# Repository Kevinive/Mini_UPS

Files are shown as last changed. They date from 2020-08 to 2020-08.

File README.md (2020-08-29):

# Mini_UPS
A Low-Voltage UPS designed for dormitory.

一个在宿舍断电后为宿舍位基本用电器供电的UPS。

### 1 项目介绍

宿舍断电后一篇漆黑，无法继续进行学习，也无法对手机、笔记本进行充电，更无法使用寝室位的内网，因此开发了这个小项目。使用一个12V的铅蓄电池储存电能，在断电后为低电压宿舍用电器供电，以此改善宿舍生活品质。

### 2 功能介绍

#### 此系统实现了以下功能：

- 电池管理：对于铅蓄电池的电量进行管理，自动评估是否需要充电，若需要充电则在白天对电池进行充电。

- 电源预切换：由于检测到断电后再对电源进行切换会造成宿舍桌面用电器重启的情况，因此通过预设定固定的计划断电时间，让系统在市电掉电之前就将电源切换至电瓶。

- 多电压输出：同时输出24V、12V和5V的电压，为多种用电器供电。

#### 此系统还可实现以下功能：

- 联网控制：通过无线射频模块与寝室中控联络，接受统一控制。

### 3 文件介绍

ProgramBrief.docx ： 项目的具体设计细节

#### src/ ： 主程序代码相关文件

- UPSMain.ino ： 主程序

- UPS_config.h ： 若干UPS控制参数

- OLED.cpp/.h ： OLED屏驱动库

- WDTwake.cpp/.h ： 使用看门狗计数器唤醒程序的功能库

- NRF24L01forArduino.cpp/.h ： 无线通信模块驱动库（待开发）

#### lib/ ： 驱动库

#### circuit/ ： 电路设计文件

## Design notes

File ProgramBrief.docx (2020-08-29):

1系统模块图：

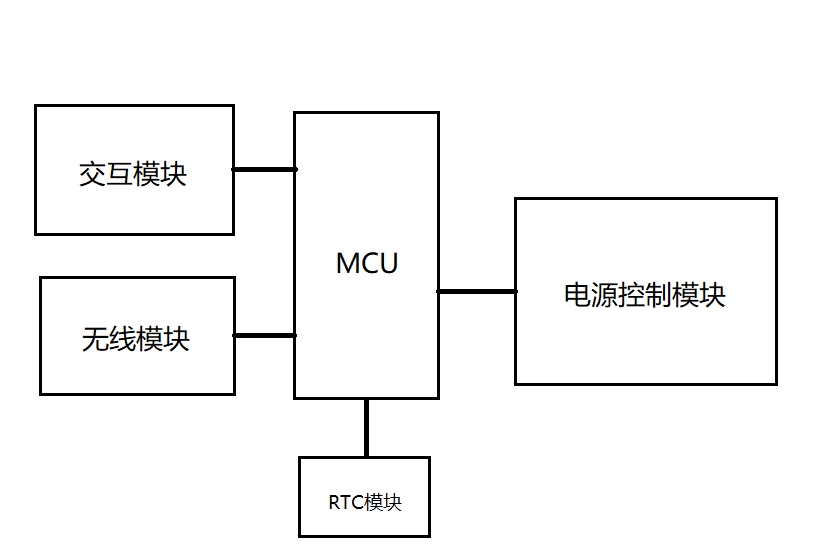
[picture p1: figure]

2模块功能要求：

1） 电源控制模块要求：在MCU的控制下进行电源切换；在MCU的控制下对电瓶进行充电（充电与停止充电）；在MCU的控制下对单片机进行断电（防止电瓶过放）；在外部按钮的控制下对MCU进行启动（MCU断电情况下无法自启动）；对MCU供电；（显示当前电量）（可以不实现）；
2） MCU：从RTC获取信号；根据时间控制电源模块进行电源切换；根据电瓶电压控制电源模块对电瓶进行充电（充电与停止充电）；在无电源且电瓶过放的情况下控制电源模块对自身进行断电；从无线模块接收指令并执行；通过交互界面让用户进行设定；交互界面超时熄灭；
3） RTC模块：设定时间后通过中断形式给MCU发送信号；自身有准确的实时时间，自带电源。
4） 无线模块：NRF24L01
5） 交互模块：由OLED显示屏、按键组成，能够独立设置参数并保存。

电源模块设计：

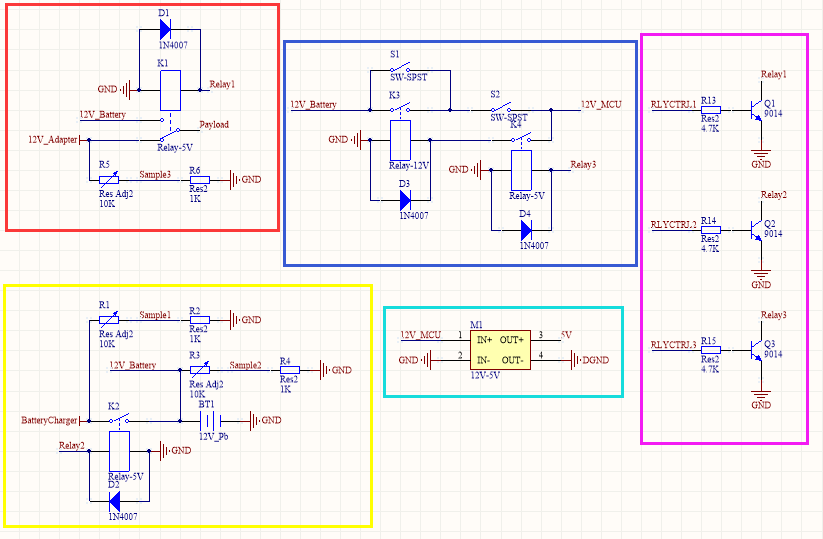
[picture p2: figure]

电源部分由一个12V的铅蓄电池、4个继电器、1个12V-5V的MCU供电模块和若干采样电阻组成。

12V电源切换部分，由一个MCU控制的5V继电器构成，控制着电源的切换（切换时间<20ms）。同时在12V电源适配器端有采样电路供单片机获取当前电压。

12V电瓶充放电电路，由一个12V铅蓄电池，一个MCU控制的继电器、电池充电器和电压采样电路组成。单片机通过电瓶电压和充电器电压采样电路可以获得相应电压，在电瓶电压不足时控制继电器吸合以为电瓶充电。

MCU供电开关电路，由两个继电器和一个开关控制，形成一个自锁开关电路。K3常开、K4常闭。一开始时K3断开，K3之后电路无电源。当按下外部开关S1后，电流流经K3控制回路，吸合K3，形成自锁，此时松开S1，后部分电路仍保持供电。当MCU检测到电瓶电压不足，为了保护电瓶，给K4控制回路上电，断开K4，使得K3断开，之后电路恢复断开的情形。

MCU电压转换电路，使用成品LM2596S芯片进行电压转换，电路成熟，可靠度高。

电流放大模块，使用三极管将控制电流放大，以实现单片机控制继电器。

RTC时钟模块：

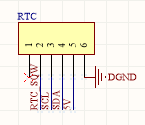
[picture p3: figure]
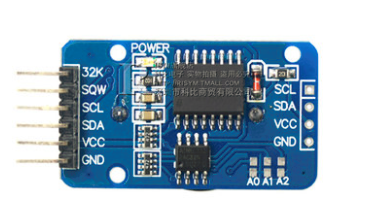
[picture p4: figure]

RTC时钟使用DS3231模块，此模块使用I2C通信，同时带有片上EEPROM。其时钟精度满足要求。工作过程中，将使用其SQW引脚向外周期发送信号，以唤醒MCU进行一系列的工作任务。同时提供矫正过的真实世界时间数据。

无线模块：

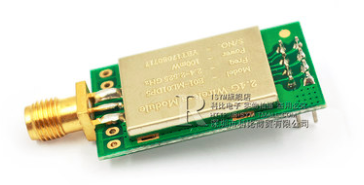
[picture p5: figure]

使用NRF24L01与主控设备或其他设备进行通信，同时可接收远程指令，包括但不限于：校准时间、手动断电、更改计划等。

交互模块：

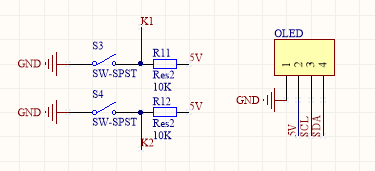
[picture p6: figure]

交互模块由一个OLED显示屏与两个按键组成。OLED屏选择使用I2C接口的128*64标准OLED，最大化利用I2C总线。按键S2和S3通过一段接地，另一端接MCU的输入端口，MCU输入端口提供上拉。

MCU：

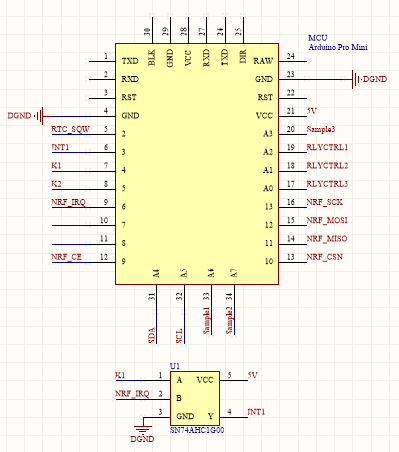
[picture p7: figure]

MCU选择Arduino pro mini 这款微型开发板。其核心为8位ATMega328P主控芯片，并且将最小系统已经集成在板上，十分适合快速开发。片上也有硬件SPI与硬件I2C接口，在同等级MCU中资源比较丰富。

ATMega328P这款芯片有两个外部中断引脚，在电平跳变激活中断的设置下，可以实现将MCU从掉电模式唤醒。但是本系统需要支持3路外部唤醒信号：RTC中断、无线系统中断、S2中断。因此，根据其中断特性，使用一个与非门将无线系统中断和S2中断连接到同一个中端口，将RTC中断单独连接到一个中断口。

V1版本

具体实现：

模块名称 | 模块 | PIN | 备注
OLED | SDA | 7 | OLED使用软件I2C通信，有外部上拉
| SCL | 8
NRF | MOSI | 11 | NRF使用硬件SPI通信
| MISO | 12
| SCK | 13
| CSN | 10
| CE | 9 | 芯片使能引脚
| IRQ | 3 | NRF中断输入MCU中断引脚3
RLY | RLY1 | 16A2 | RLY使用模拟口作为数字输出
| RLY2 | 15A1
| RLY3 | 14A0
SMP | S1 | A6 | 电压信号输入
| S2 | A7
| S3 | A3
KEY | K1 | 2 | 作为中断输入MCU中断引脚2
| K2 | 4 | 作为普通输入MCU

中断资源：

中断源 | 中断作用
NRF-IRQ | 唤醒MCU；传输数据；控制
K1 | 唤醒MCU；人机交互；控制
WDT | 唤醒MCU；采集电压信息&时间信息；控制

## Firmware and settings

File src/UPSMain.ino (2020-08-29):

#include "Include.h"

uint8 UPS_rxAdd[] = {0x11,0x22,0x33,0x44,0x55};		//通道1的接收地址
uint8 Master_txAdd[] = {1,2,3,4,5};
uint8 nrfDataBuf[RXBUFSIZE] = {0};
uint8 displayFlag = 1;					//此变量置一之后表明人机互动开始，置0则表示人机互动结束
uint8 needCalibrate = 1;				//时间需要校准变量 每次系统重启都会提示，直到重新设置了时间为止。
uint8 systemState = 0;					//系统状态bit，按照以下规则定义
uint16 chargeStartTime = 0;			//记录充电开始的时间 (min)
uint16 sysCount = 0;

//定义电压标准，后期要调整
uint16 adapter_refVoltage = REF_VOLTAGE;
uint16 battery_fullVoltage = REF_BATFULL_VOLTAGE;
uint16 battery_emptyVoltage = REF_BATEMPTY_VOLTAGE;
uint16 battery_needChargeVoltage = REF_BATNEEDCHG_VOLTAGE;
uint16 maxChargeTime = CHARGER_TIME;

/*
Bit		7		6		5		4		3		2		1		Func
									ICH	CHG	PW1	PW0
ICH(is Charge Needed)：	是否正在充电？				0否1是
CHG(Charge)：						电池是否需要充电？		0否1是
PW1&PW0(PowerState):		系统电源？						00市电	01电池	10断电：电池保护

*/

uint8 wakeCount = 0;


RTCTime currentTime = {0,48,20,25,9,18,0};
RTCTime AlarmTime[2] = {{0,55,22,0,0,0,0},{0,0,0,0,0,0,0}};			//初始化值为22：55分的闹钟一个。如果结构体全为0则不设置闹钟。

bool h12,hPM;
DS3231 Clock;				//对象申明

VoltInfo volInfo[3] = {6,"Adapter",0,
											 7,"Charger",0,
											 3,"Battery",0};

uint16 U_Adapter, U_Charger, U_Battery;

void setup(){
	NRF24L01_InitTypeDef NRF24L01_InitStructure;
	
	pinMode(RELAY1_PIN,OUTPUT);
	pinMode(RELAY2_PIN,OUTPUT);
	pinMode(RELAY3_PIN,OUTPUT);
	
	//digitalWrite(RELAY3_PIN,1);				//因为板子原因此功能暂停
	switchToAdapter();
	turnOffCharger();
	
	//NRF模块初始化（包含SPI初始化）
  NRF24L01_init();
  NRF24L01_InitStructure.IR_MASK = NRF24L01_MASK_RX_DR|NRF24L01_MASK_TX_DS|NRF24L01_MASK_MAX_RT;
  NRF24L01_InitStructure.CRC_CONFIG = NRF24L01_CRC_EN|NRF24L01_CRC_8bit;
  NRF24L01_InitStructure.EN_AA = NRF24L01_ENAA_ALL;
  NRF24L01_InitStructure.EN_RXADDR = NRF24L01_ERX_P0|NRF24L01_ERX_P1;
  NRF24L01_InitStructure.AW = NRF24L01_AW_5b;
  NRF24L01_InitStructure.RETR_ARD = NRF24L01_RETR_ARD_1000us;
  NRF24L01_InitStructure.RETR_ARC = 3;
  NRF24L01_InitStructure.RF_CH = NRF24L01_RF_CH_DEFAULT;
  NRF24L01_InitStructure.RF_DR = NRF24L01_RF_DR_2M;
  NRF24L01_InitStructure.RF_PWR = NRF24L01_RF_PWR_0;
  NRF24L01_InitStructure.RX_ADDR[0] = Master_txAdd;
  NRF24L01_InitStructure.RX_ADDR[1] = UPS_rxAdd;
  NRF24L01_InitStructure.RX_PW[0] = RXBUFSIZE;
  NRF24L01_InitStructure.RX_PW[1] = RXBUFSIZE;
  NRF24L01_config(&NRF24L01_InitStructure);
	
	Serial.begin(115200);
	//I2C初始化
  Wire.begin();
	OLED_Config();
	
	OLED_Write_Str16X8(0,0,"SOURCE:");
	OLED_Write_Str16X8(1,0,"Adapter:");
	OLED_Write_Str16X8(2,0,"Charger:");
	OLED_Write_Str16X8(3,0,"Battery:");
	
	//RTC初始化（不包含I2C初始化）
  //RTC一直处于运行当中，无需初始化。所需要的设置仅为时间的设定。
  //此处设置RTC的时钟属性
	/*Clock.setSecond(currentTime.second);//Set the second 
	Clock.setMinute(currentTime.minute);//Set the minute 
	Clock.setHour(currentTime.hour);  //Set the hour 
	Clock.setDoW(currentTime.DoW);    //Set the day of the week
	Clock.setDate(currentTime.date);  //Set the date of the month
	Clock.setMonth(currentTime.month);  //Set the month of the year
	Clock.setYear(currentTime.year);  //Set the year (Last two digits of the year)
	*/
	
	currentTime.second = Clock.getSecond();
	currentTime.minute = Clock.getMinute();
  currentTime.hour = Clock.getHour(h12, hPM);
  currentTime.date = Clock.getDate();
  currentTime.month = Clock.getMonth(h12);
  currentTime.year = Clock.getYear();
  
  //此处设置RTC的闹钟属性
  Clock.setA1Time(AlarmTime[0].date, AlarmTime[0].hour, AlarmTime[0].minute, AlarmTime[0].second, ALM1BIT_HMS, false, false, false); 
  Clock.setA2Time(AlarmTime[1].date, AlarmTime[1].hour, AlarmTime[1].minute, ALM2BIT_HMS, false, false, false);
  if(AlarmTime[0].second | AlarmTime[0].hour | AlarmTime[0].minute | AlarmTime[0].date | AlarmTime[0].month | AlarmTime[0].year)
  	Clock.turnOnAlarm(1);
  else
  	Clock.turnOffAlarm(1);
  	
  if(AlarmTime[1].second | AlarmTime[1].hour | AlarmTime[1].minute | AlarmTime[1].date | AlarmTime[1].month | AlarmTime[1].year)
  	Clock.turnOnAlarm(2);
  else
  	Clock.turnOffAlarm(2);
  
  if(EEPROM.read(0) == 0xA8){
  	adapter_refVoltage = EEPROM.read(1)<<8;
  	adapter_refVoltage |= EEPROM.read(2);
		battery_fullVoltage = EEPROM.read(3)<<8;
		battery_fullVoltage |= EEPROM.read(4);
		battery_emptyVoltage = EEPROM.read(5)<<8;
		battery_emptyVoltage |= EEPROM.read(6);
		maxChargeTime = EEPROM.read(7)<<8;
		maxChargeTime |= EEPROM.read(8);
		battery_needChargeVoltage = EEPROM.read(9)<<8;
		battery_needChargeVoltage |= EEPROM.read(10);
  }else{
  	EEPROM.write(0, 0xA8);
  	EEPROM.write(1, (char)(adapter_refVoltage>>8));
  	EEPROM.write(2, (char)(adapter_refVoltage&0xff));
  	EEPROM.write(3, (char)(battery_fullVoltage>>8));
  	EEPROM.write(4, (char)(battery_fullVoltage&0xff));
  	EEPROM.write(5, (char)(battery_emptyVoltage>>8));
  	EEPROM.write(6, (char)(battery_emptyVoltage&0xff));
  	EEPROM.write(7, (char)(maxChargeTime>>8));
  	EEPROM.write(8, (char)(maxChargeTime&0xff));
  	EEPROM.write(9, (char)(battery_needChargeVoltage>>8));
  	EEPROM.write(10, (char)(battery_needChargeVoltage&0xff));
  }
  
	WDTwake_init();
}

void loop(){
	//此处放采集函数
	getVoltages();
	if(wakeCount >= 8){			//苏醒间隔8秒，八次苏醒读取一次时间，将近一分钟
		currentTime.second = Clock.getSecond();
		currentTime.minute = Clock.getMinute();
  	currentTime.hour = Clock.getHour(h12, hPM);
  	currentTime.date = Clock.getDate();
  	currentTime.month = Clock.getMonth(h12);
  	currentTime.year = Clock.getYear();
  	wakeCount = 0;
	}
	batteryManager();
	wakeCount++;
	sysCount++;
	OLED_Write_Num16X8(0,0,sysCount);
	OLED_Write_Num16X8(0,10,systemState);
  OLED_Write_Num16X8(1,10,volInfo[0].value);
  OLED_Write_Num16X8(2,10,volInfo[1].value);
  OLED_Write_Num16X8(3,10,volInfo[2].value);
	
	//此处放置所有人机交互界面的相关代码
  /*if(displayFlag){
  	
  	
  	attachInterrupt(digitalPinToInterrupt(2),UPS_Int0_Handler,CHANGE);			//最后将中断使能
  	displayFlag = 0;
  }
  */
  
  //如果有数据传入
  //NRF24L01_PrintState();
	if(NRF24L01_getStatus() & NRF24L01_STATU_RX_DR){
		NRF24L01_recieve(nrfDataBuf);			//接收数据
		
		if(nrfDataBuf[0] == UPS_rxAdd[4] && nrfDataBuf[1] == UPS_rxAdd[3] && nrfDataBuf[2] == UPS_rxAdd[2] && nrfDataBuf[3] == UPS_rxAdd[1] && nrfDataBuf[4] == UPS_rxAdd[0]){
			//赋值
			adapter_refVoltage = ((uint16)nrfDataBuf[5])<<8 | nrfDataBuf[6];
			battery_fullVoltage = ((uint16)nrfDataBuf[7])<<8 | nrfDataBuf[8];
			battery_emptyVoltage = ((uint16)nrfDataBuf[9])<<8 | nrfDataBuf[10];
			maxChargeTime = ((uint16)nrfDataBuf[11])<<8 | nrfDataBuf[12];
			battery_needChargeVoltage = ((uint16)nrfDataBuf[13])<<8 | nrfDataBuf[14];
			
			//存储
			EEPROM.write(1, (char)(adapter_refVoltage>>8));
	  	EEPROM.write(2, (char)(adapter_refVoltage&0xff));
	  	EEPROM.write(3, (char)(battery_fullVoltage>>8));
	  	EEPROM.write(4, (char)(battery_fullVoltage&0xff));
	  	EEPROM.write(5, (char)(battery_emptyVoltage>>8));
	  	EEPROM.write(6, (char)(battery_emptyVoltage&0xff));
	  	EEPROM.write(7, (char)(maxChargeTime>>8));
	  	EEPROM.write(8, (char)(maxChargeTime&0xff));
	  	EEPROM.write(9, (char)(battery_needChargeVoltage>>8));
  		EEPROM.write(10, (char)(battery_needChargeVoltage&0xff));
			
			//以下为测试程序
			OLED_Write_Num16X8(0,10,maxChargeTime);
			OLED_Write_Num16X8(1,10,adapter_refVoltage);
  		OLED_Write_Num16X8(2,10,battery_fullVoltage);
  		OLED_Write_Num16X8(3,10,battery_emptyVoltage);
			OLED_Write_Str16X8(0,10,"OK");
			OLED_Write_Str16X8(1,10,"OK");
			OLED_Write_Str16X8(2,10,"OK");
			OLED_Write_Str16X8(3,10,"OK");
		}
		//清空缓冲区
		memset(nrfDataBuf, 0, sizeof(nrfDataBuf));
	}
	
	
	
  Serial.print(currentTime.year);
  Serial.print(".");
  Serial.print(currentTime.month);
  Serial.print(".");
  Serial.println(currentTime.date);
  
  Serial.print("time:\t");
  Serial.print(currentTime.hour);
  Serial.print(":");
  Serial.print(currentTime.minute);
  Serial.print(":");
  Serial.println(currentTime.second);
  delay(50);
  
  
  /*if((systemState & UPS_STATE_PW1_MSK == 0) && (systemState & UPS_STATE_PW0_MSK == 0)){
  	OLED_Write_Str16X8(0,10,"Adap");
  }else if((systemState & UPS_STATE_PW1_MSK == 0) && (systemState & UPS_STATE_PW0_MSK)){
  	OLED_Write_Str16X8(0,10,"Batt");
  }*/
  
	WDTwake_enterSleep();
}

void getVoltages(){
	uint8 i;
	for(i=0;i<3;i++){
		volInfo[i].value = analogRead(volInfo[i].pin);
	}
	U_Adapter = volInfo[0].value;
	U_Charger = volInfo[1].value;
	U_Battery = volInfo[2].value;
	
	return;
}


//电源管理逻辑
/*
Bit		7		6		5		4		3		2		1		Func
									ICH	CHG	PW1	PW0
ICH(is Charge Needed)：	是否正在充电？				0否1是
CHG(Charge)：						电池是否需要充电？		0否1是
PW1&PW0(PowerState):		系统电源？						00市电	01电池	10断电：电池保护

*/
void batteryManager(){
	switch(systemState & (UPS_STATE_PW1_MSK | UPS_STATE_PW0_MSK)){
		case 0:				//当前供电为市电
			if(U_Adapter > adapter_refVoltage){		//电源适配器有电
				if(((uint16)currentTime.hour*60 + currentTime.minute) > ((uint16)AlarmTime[0].hour*60 + AlarmTime[0].minute) && (systemState & UPS_STATE_CHG_MSK) == 0){
					switchToBat();
				}
				if(U_Battery < battery_needChargeVoltage){
					turnOnCharger();
					chargeStartTime = ((uint16)currentTime.hour*60 + currentTime.minute);
				}
				if((UPS_STATE_ICH_MSK & systemState) && (((uint16)currentTime.hour*60 + currentTime.minute) > (chargeStartTime + maxChargeTime))){
					turnOffCharger();
					systemState &= ~UPS_STATE_CHG_MSK;
				}
			}else if((systemState & UPS_STATE_CHG_MSK) == 0){		//电源适配器没电且电池有电
				switchToBat();
			}else{				//电源适配器没电且电池没电
				
			}
			break;
		case 1:				//当前供电为电池供电
			if(U_Adapter > adapter_refVoltage && ((uint16)currentTime.hour*60 + currentTime.minute) < ((uint16)AlarmTime[0].hour*60 + AlarmTime[0].minute)){
				switchToAdapter();
				//turnOnCharger();			//每次从电池切换过来就自动开启充电器充电（这样充电对电池不好）
				//chargeStartTime = ((uint16)currentTime.hour*60 + currentTime.minute);
			}else if(U_Battery < battery_emptyVoltage){
				switchToAdapter();
				systemState |= 0x06;				//切换至断电模式
				systemState &= ~0x01;
			}else{
				
			}
			break;
		case 2:				//当前为断电情况因电池保护
			if(U_Charger > adapter_refVoltage){
				turnOnCharger();
				chargeStartTime = currentTime.hour;
				systemState &= ~0x07;
			}
			break;
		default:
			break;
	}
}

void switchToBat(){
	digitalWrite(RELAY1_PIN,1);
	systemState |= 0x01;
	systemState &= ~0x02;
}

void switchToAdapter(){
	digitalWrite(RELAY1_PIN,0);
	systemState &= ~0x03;
}

void turnOnCharger(){
	digitalWrite(RELAY2_PIN,1);
	systemState |= 0x08;
}

void turnOffCharger(){
	digitalWrite(RELAY2_PIN,0);
	systemState &= ~0x08;
}

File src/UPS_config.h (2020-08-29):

#ifndef __UPS_CONFIG_H
#define __UPS_CONFIG_H
#include "Include.h"

#define uint8			unsigned char
#define uint16		unsigned int
#define uint32		unsigned long
#define int8			char
#define int16			int
#define int32			long

#define K1_PIN					2
#define K2_PIN					4
#define RELAY1_PIN			16
#define RELAY2_PIN			15
#define RELAY3_PIN			14
#define SAMPLE1_PIN			6			//12.5=850
#define SAMPLE2_PIN			7			//12.5=850
#define SAMPLE3_PIN			3			//12.5=850
#define OLED_SCL				8
#define OLED_SDA				7

#define OLED_ADDR				0X78
#define EEPROM_ADDR			0X57

#define ALM1BIT_HMS			0X08
#define ALM2BIT_HMS			0X40

#define RXBUFSIZE 			32

#define REF_VOLTAGE							800					//阈值电压AD值，低于此则认为电压为0 否则有电（仅用于Charger&Adapter）
#define REF_BATEMPTY_VOLTAGE		720					//阈值电压AD值，低于此认为电池没电，关断输出，并将需要充电标志置位。
#define REF_BATFULL_VOLTAGE			1000					//阈值电压AD值，充电过程中高于此认为电池充满，结束充电过程。
#define CHARGER_TIME						360					//充电时间（经验值）(min)
#define REF_BATNEEDCHG_VOLTAGE	811

#define UPS_STATE_ICH_MSK				0X08
#define UPS_STATE_CHG_MSK				0X04
#define UPS_STATE_PW1_MSK				0X02
#define UPS_STATE_PW0_MSK				0X01

typedef struct DS3231time{
	uint8 second;
	uint8 minute;
	uint8 hour;
	uint8 date;
	uint8 month;
	uint8 year;
	uint8 DoW;
} RTCTime;

typedef struct VoltageInfo{
	uint8 pin;
	const uint8 *displayName;
	uint16 value;
} VoltInfo;

extern RTCTime currentTime;
extern RTCTime AlarmTime[2];

extern VoltInfo volInfo[3];
extern uint16 U_Adapter, U_Charger, U_Battery;

extern void getVoltages();

#endif
